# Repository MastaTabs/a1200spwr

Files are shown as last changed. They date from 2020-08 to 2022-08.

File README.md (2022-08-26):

# Amiga1200 single power

This is a DCDC converter Module to fit in Rev. 6a+ Amiga 500 mainboards.
It will be soldered onto the mainboard and one can then use a 12V barrel jack power supply with the Amiga 500.

It can deliver upto 6A @ 5V and 500mA @ -12V. The 12V line is passed through.

It also adds a power switch to the machine on the backside.

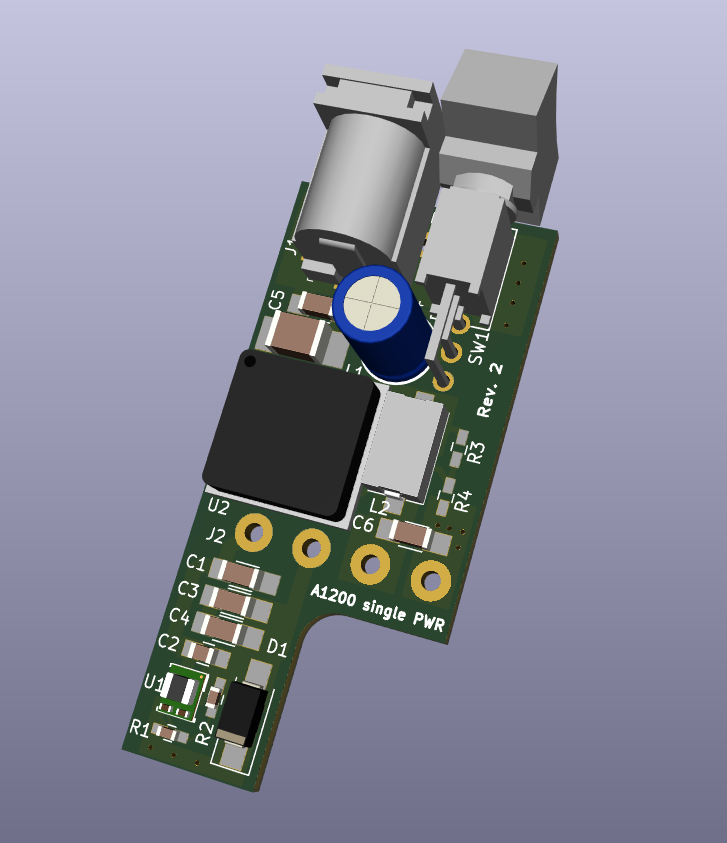
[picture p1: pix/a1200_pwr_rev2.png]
A1200


This design has not been finally tested yet.

### License
The Amiga1200 single power documentation, including the design itself, is copyright © MastaTabs (Tobias Seiler) 2020.

Amiga1200 single power is Open Hardware licensed under the CERN OHL v. 1.2.

You may redistribute and modify this documentation under the terms of the CERN OHL v.1.2. This documentation is distributed as is and WITHOUT ANY EXPRESS OR IMPLIED WARRANTIES whatsoever with respect to its functionality, operability or use, including, without limitation, any implied warranties OF MERCHANTABILITY, SATISFACTORY QUALITY, FITNESS FOR A PARTICULAR PURPOSE or infringement. We expressly disclaim any liability whatsoever for any direct, indirect, consequential, incidental or special damages, including, without limitation, lost revenues, lost profits, losses resulting from business interruption or loss of data, regardless of the form of action or legal theory under which the liability may be asserted, even if advised of the possibility or likelihood of such damages.

A copy of the full license is included in file LICENSE.pdf, please refer to it for applicable conditions. In order to properly deal with its terms, please see file LICENSE_HOWTO.pdf.

The contact points for information about manufactured Products (see section 4.2) are listed in file PRODUCT.md.

Any modifications made by Licensees (see section 3.4.b) shall be recorded in file CHANGES.md.

The Documentation Location of the original project is https://github.com/MastaTabs/a1200spwr.

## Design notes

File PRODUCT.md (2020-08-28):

## Manufacture and distribution of Products

Amiga1200 single power is Open Hardware licensed under the CERN OHL v. 1.2.

Following is an excerpt from Section 4 of the [license](LICENSE.pdf) - **Manufacture and distribution of Products** - where *product* means *either an entire, or any part of a, device built using the Documentation or the modified Documentation*:

> 4.1. The Licensee may manufacture or distribute *Products* always provided that, where such manufacture or distribution requires a licence under this Licence the Licensee provides to each recipient of such Products an easy means of accessing a copy of the Documentation or modified Documentation, as applicable, as set out in section 3.

> 4.2. The Licensee is invited to inform any Licensor who has indicated his wish to receive this information about the type, quantity and dates of production of Products the Licensee has (had) manufactured

This file contains a list of the contact point wishing to receive information about manufactured Products.

### (Name) (E-Mail or other contact details)
- MastaTabs <mastatabs@gmail.com>

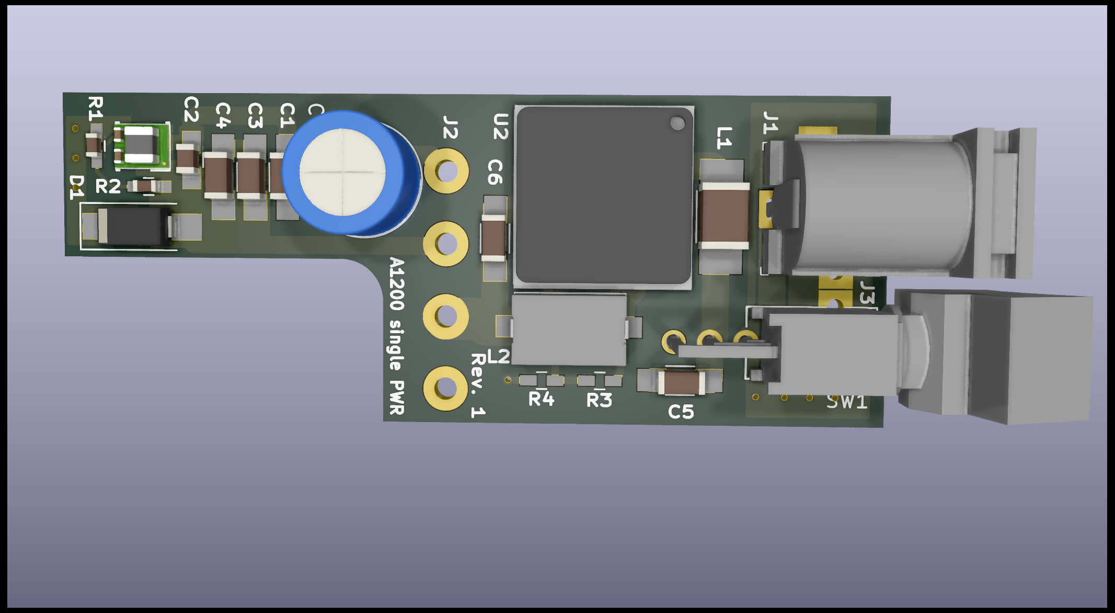
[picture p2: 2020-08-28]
pix/a1200_pwr1.png

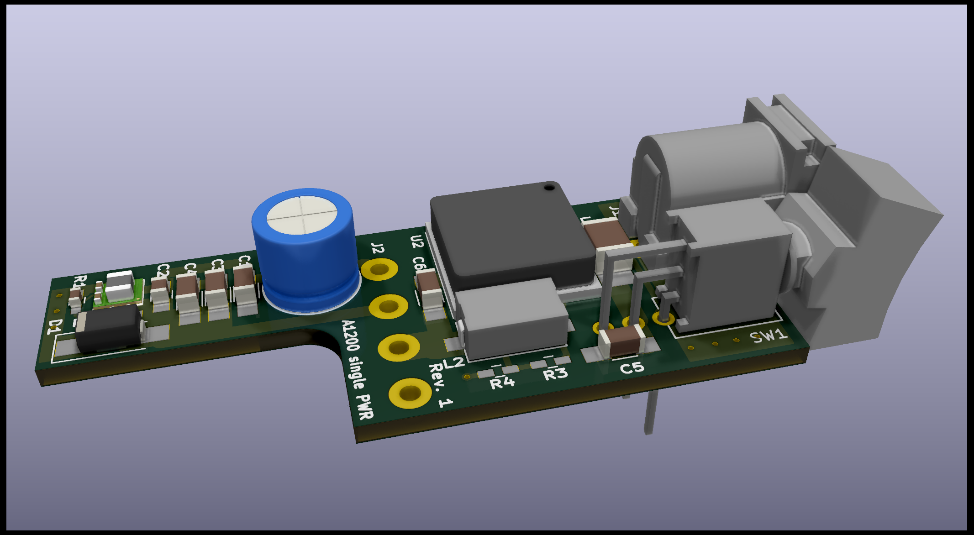
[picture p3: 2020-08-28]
pix/a1200_pwr.png

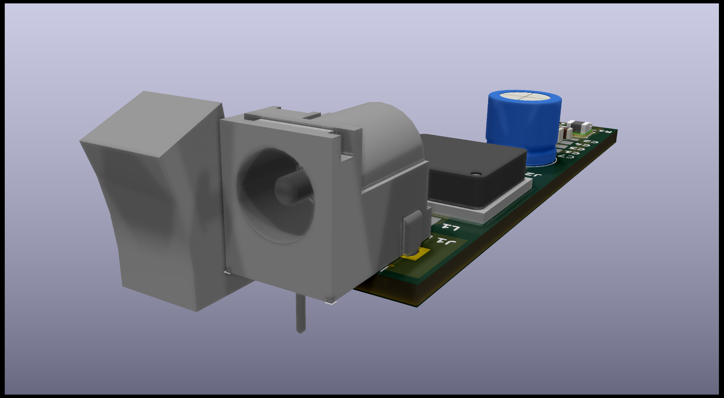
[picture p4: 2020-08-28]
pix/a1200_pwr2.png

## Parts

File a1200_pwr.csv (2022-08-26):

Source: | /home/masta/Desktop/projects/a1200_power/a1200_pwr/a1200_pwr.kicad_sch
Date: | Fr 26 Aug 2022 22:16:40 CEST
Tool: | Eeschema (6.0.7)
Generator: | /usr/share/kicad/plugins/bom_csv_grouped_by_value.py
Component Count: | 20
Individual Components:
<<<<<<< HEAD
Item | Qty | Reference(s) | Value | LibPart | Footprint | Datasheet | Category | DK_Datasheet_Link | DK_Detail_Page | Description | Digi-Key_PN | Family | Herstellernr. | MPN | Manufacturer | Status
 |  | C1 | 10u 25V | Device:C_Small | Capacitors_SMD:C_1206_HandSoldering | https://www.mouser.de/datasheet/2/400/lcc_commercial_general_en-837201.pdf |  |  |  |  |  |  | C3216X5R1H106K160AB
 |  | C2 | 100n 50V | Device:C_Small | Capacitors_SMD:C_0805_HandSoldering | C2012X7R2A104K125AA
 |  | C3 | 10u | Device:C_Small | Capacitors_SMD:C_1206_HandSoldering | CGA5L1X7R1V106K160AC
 |  | C4 | 10u | Device:C_Small | Capacitors_SMD:C_1206_HandSoldering | CGA5L1X7R1V106K160AC
 |  | C5 | 10u 25V | Device:C_Small | Capacitors_SMD:C_1206_HandSoldering | C3216X5R1H106K160AB
 |  | C6 | 22u | Device:C_Small | Capacitors_SMD:C_1206_HandSoldering | C3216X5R1V226M160AC
 |  | C7 | 330u | Device:C | Capacitors_THT:CP_Radial_D8.0mm_P3.50mm | ~
 |  | D1 | 700mV | Device:D_Schottky_Small | Diodes_SMD:D_SMA_Handsoldering | B360A-13-F
 |  | J1 | PJ-102A | barreljack:PJ-102A | a1200_pwr:Barrel_Jack_5.5mmODx2.1mmID_PJ-102A | https://www.cui.com/product/resource/digikeypdf/pj-102a.pdf | Connectors, Interconnects | https://www.cui.com/product/resource/digikeypdf/pj-102a.pdf | /product-detail/en/cui-inc/PJ-102A/CP-102A-ND/275425 | CONN PWR JACK 2X5.5MM SOLDER | CP-102A-ND | Barrel - Power Connectors |  | PJ-102A | CUI Inc. | Active
 |  | J2 | APWR_big | a1200_pwr-rescue:Conn_01x04-connect | a1200_pwr:APWR_big | ~
 |  | J3 | APWR_small | a1200_pwr-rescue:Conn_01x03-connect | a1200_pwr:APWR_small | ~ | Connectors, Headers
 |  | L1 | 742792510 | Device:Ferrite_Bead_Small | Capacitors_SMD:C_1812_HandSoldering | https://www.mouser.de/datasheet/2/445/742792510-1720733.pdf |  |  |  |  |  |  |  |  | Würth
 |  | L2 | 7427932 | Device:Ferrite_Bead_Small | a500_pwr:fb_5v | https://www.mouser.de/datasheet/2/445/7427932-1720978.pdf |  |  |  |  |  |  |  |  | Würth
 |  | R1 | 280k 1% | Device:R_Small | Capacitors_SMD:C_0603_HandSoldering | https://www.mouser.de/datasheet/2/427/dcrcwe3-45987.pdf |  |  |  |  |  |  | CRCW0603280KFKEA
 |  | R2 | 25.5k | Device:R_Small | Capacitors_SMD:C_0603_HandSoldering | https://www.mouser.de/datasheet/2/427/dcrcwe3-45987.pdf |  |  |  |  |  |  | CRCW060325K5FKEA
 |  | R3 | Rdown | Device:R_Small | Capacitors_SMD:C_0603_HandSoldering
 |  | R4 | Rup | Device:R_Small | Capacitors_SMD:C_0603_HandSoldering
 |  | SW1 | RMS1R102M7QES | a1200_pwr:PWR_SW | a1200_pwr:rock_sw | https://www.mouser.de/datasheet/2/418/NG_CD_2267087_A_2267087_c.dwg-680380.pdf
 |  | U1 | LMZM23600SILR | a1200_pwr:LMZM23601SILR | a1200_pwr:SIL0010A | http://www.ti.com/general/docs/suppproductinfo.tsp?distId=26
 |  | U2 | RPM5.0-6.0 | a1200_pwr:RPM5.0-6.0 | a1200_pwr:RPM5.0-6.0 | https://www.mouser.de/datasheet/2/468/RPM-6.0-1398219.pdf
=======
Item | Qty | Reference(s) | Value | LibPart | Footprint | Datasheet | Category | DK_Datasheet_Link | DK_Detail_Page | Datasheet | Description | Digi-Key_PN | Family | MPN | Manufacturer | Reference | Status | Value
 |  | C1 | 10u 25V | Device:C_Small |  | https://www.mouser.de/datasheet/2/400/lcc_commercial_general_en-837201.pdf |  |  |  | https://www.mouser.de/datasheet/2/400/lcc_commercial_general_en-837201.pdf |  |  |  | C3216X5R1H106K160AB |  | C1 |  | C_Small
 |  | C2 | 100n 50V | Device:C_Small |  | C2012X7R2A104K125AA |  |  |  | ~ |  |  |  | C2012X7R2A104K125AA |  | C2 |  | C_Small
 |  | C3 | 10u | Device:C_Small |  | CGA5L1X7R1V106K160AC |  |  |  | ~ |  |  |  | CGA5L1X7R1V106K160AC |  | C3 |  | C_Small
 |  | C4 | 10u | Device:C_Small |  | CGA5L1X7R1V106K160AC |  |  |  | ~ |  |  |  | CGA5L1X7R1V106K160AC |  | C4 |  | C_Small
 |  | C5 | 10u 50V | Device:C_Small | Capacitors_SMD:C_1206_HandSoldering | C3216X5R1H106K160AB |  |  |  | ~ |  |  |  | C3216X5R1H106K160AB |  | C5 |  | 10u 50V
 |  | C6 | 22u 35V | Device:C_Small | Capacitors_SMD:C_1206_HandSoldering | https://product.tdk.com/system/files/dam/doc/product/capacitor/ceramic/mlcc/catalog/mlcc_commercial_general_en.pdf |  |  |  | https://product.tdk.com/system/files/dam/doc/product/capacitor/ceramic/mlcc/catalog/mlcc_commercial_general_en.pdf |  |  |  | C3216X5R1C226M160AB | TDK | C6 |  | 22u 35V
 |  | C7 | 330u | Device:C | Capacitor_THT:CP_Radial_D6.3mm_P2.50mm | https://www.mouser.de/datasheet/2/445/860160373021-1725922.pdf |  |  |  | https://www.mouser.de/datasheet/2/445/860160373021-1725922.pdf |  |  |  | 860160373021 | Wuerth | C7 |  | 330u
 |  | D1 | 700mV | Device:D_Schottky_Small |  | B360A-13-F |  |  |  | ~ |  |  |  | B360A-13-F | Diodes Incorporated | D1 |  | D_Schottky_Small
 |  | J1 | PJ-102A | barreljack:PJ-102A | digikey-footprints:Barrel_Jack_5.5mmODx2.1mmID_PJ-102A | https://www.cui.com/product/resource/digikeypdf/pj-102a.pdf | Connectors, Interconnects | https://www.cui.com/product/resource/digikeypdf/pj-102a.pdf | /product-detail/en/cui-inc/PJ-102A/CP-102A-ND/275425 | https://www.cui.com/product/resource/digikeypdf/pj-102a.pdf | CONN PWR JACK 2X5.5MM SOLDER | CP-102A-ND | Barrel - Power Connectors | PJ-102A | CUI Inc. | J1 | Active | PJ-102A
 |  | J2 | APWR_big | a1200_pwr-rescue:Conn_01x04-connect |  |  |  |  |  |  |  |  |  |  |  | J2 |  | Conn_01x04-connect
 |  | J3 | APWR_small | a1200_pwr-rescue:Conn_01x03-connect |  |  | Connectors, Headers |  |  |  |  |  |  |  |  | J3 |  | Conn_01x03-connect
 |  | L1 | 742792510 | a1200_pwr-rescue:Ferrite_Bead_Small-Device | Capacitors_SMD:C_1812_HandSoldering | https://www.mouser.de/datasheet/2/445/742792510-1720733.pdf |  |  |  | https://www.mouser.de/datasheet/2/445/742792510-1720733.pdf |  |  |  | 742792510 | Würth | L1 |  | 742792510
 |  | L2 | 7427932 | a1200_pwr-rescue:Ferrite_Bead_Small-Device | a500_pwr:fb_5v | https://www.mouser.de/datasheet/2/445/7427932-1720978.pdf |  |  |  | https://www.mouser.de/datasheet/2/445/7427932-1720978.pdf |  |  |  | 7427932 | Würth | L2 |  | 7427932
 |  | R1 | 280k 1% | Device:R_Small |  | https://www.mouser.de/datasheet/2/427/dcrcwe3-45987.pdf |  |  |  | https://www.mouser.de/datasheet/2/427/dcrcwe3-45987.pdf |  |  |  | CRCW0603280KFKEA |  | R1 |  | R_Small
 |  | R2 | 25.5k | Device:R_Small |  | https://www.mouser.de/datasheet/2/427/dcrcwe3-45987.pdf |  |  |  | https://www.mouser.de/datasheet/2/427/dcrcwe3-45987.pdf |  |  |  | CRCW060325K5FKEA |  | R2 |  | R_Small
 |  | R3 | Rdown | Device:R_Small |  | ~ |  |  |  | ~ |  |  |  |  |  | R3 |  | R_Small
 |  | R4 | Rup | Device:R_Small |  | ~ |  |  |  | ~ |  |  |  |  |  | R4 |  | R_Small
 |  | SW1 | SW_SPDT | Switch:SW_SPDT | a1200_pwr:rock_sw | https://www.mouser.de/datasheet/2/418/NG_CD_2267087_A_2267087_c.dwg-680380.pdf |  |  |  | https://www.mouser.de/datasheet/2/418/NG_CD_2267087_A_2267087_c.dwg-680380.pdf |  |  |  | RMS1R102M7QES |  | SW1 |  | SW_SPDT
 |  | U1 | LMZM23600SILR | a1200_pwr-rescue:LMZM23601SILR-a1200_pwr |  | http://www.ti.com/general/docs/suppproductinfo.tsp?distId=26 |  |  |  | http://www.ti.com/general/docs/suppproductinfo.tsp?distId=26 |  |  |  | lmzm23600 | Texas Instruments | U1 |  | LMZM23601SILR-a1200_pwr
 |  | U2 | RPM5.0-6.0 | a1200_pwr:RPM5.0-6.0 | a500_pwr:RPM5.0-6.0 | https://www.mouser.de/datasheet/2/468/RPM-6.0-1398219.pdf |  |  |  | https://www.mouser.de/datasheet/2/468/RPM-6.0-1398219.pdf |  |  |  | RPM5.0-6.0 | RECOM Power | U2 |  | RPM5.0-6.0
>>>>>>> bf3d058 (Revision 2)
Collated Components:
Item | Qty | Reference(s) | Value | LibPart | Footprint | Datasheet | Category | DK_Datasheet_Link | DK_Detail_Page | Datasheet | Description | Digi-Key_PN | Family | MPN | Manufacturer | Reference | Status | Value
1 | 1 | C1 | 10u 25V | Device:C_Small |  | https://www.mouser.de/datasheet/2/400/lcc_commercial_general_en-837201.pdf |  |  |  | https://www.mouser.de/datasheet/2/400/lcc_commercial_general_en-837201.pdf |  |  |  | C3216X5R1H106K160AB |  | C1 |  | C_Small
2 | 1 | C2 | 100n 50V | Device:C_Small |  | C2012X7R2A104K125AA |  |  |  | ~ |  |  |  | C2012X7R2A104K125AA |  | C2 |  | C_Small
3 | 2 | C3, C4 | 10u | Device:C_Small |  | CGA5L1X7R1V106K160AC |  |  |  | ~ |  |  |  | CGA5L1X7R1V106K160AC |  | C3 |  | C_Small
4 | 1 | C5 | 10u 50V | Device:C_Small | Capacitors_SMD:C_1206_HandSoldering | C3216X5R1H106K160AB |  |  |  | ~ |  |  |  | C3216X5R1H106K160AB |  | C5 |  | 10u 50V
5 | 1 | C6 | 22u 35V | Device:C_Small | Capacitors_SMD:C_1206_HandSoldering | https://product.tdk.com/system/files/dam/doc/product/capacitor/ceramic/mlcc/catalog/mlcc_commercial_general_en.pdf |  |  |  | https://product.tdk.com/system/files/dam/doc/product/capacitor/ceramic/mlcc/catalog/mlcc_commercial_general_en.pdf |  |  |  | C3216X5R1C226M160AB | TDK | C6 |  | 22u 35V
6 | 1 | C7 | 330u | Device:C | Capacitor_THT:CP_Radial_D6.3mm_P2.50mm | https://www.mouser.de/datasheet/2/445/860160373021-1725922.pdf |  |  |  | https://www.mouser.de/datasheet/2/445/860160373021-1725922.pdf |  |  |  | 860160373021 | Wuerth | C7 |  | 330u
7 | 1 | D1 | 700mV | Device:D_Schottky_Small |  | B360A-13-F |  |  |  | ~ |  |  |  | B360A-13-F | Diodes Incorporated | D1 |  | D_Schottky_Small
8 | 1 | J1 | PJ-102A | barreljack:PJ-102A | digikey-footprints:Barrel_Jack_5.5mmODx2.1mmID_PJ-102A | https://www.cui.com/product/resource/digikeypdf/pj-102a.pdf | Connectors, Interconnects | https://www.cui.com/product/resource/digikeypdf/pj-102a.pdf | /product-detail/en/cui-inc/PJ-102A/CP-102A-ND/275425 | https://www.cui.com/product/resource/digikeypdf/pj-102a.pdf | CONN PWR JACK 2X5.5MM SOLDER | CP-102A-ND | Barrel - Power Connectors | PJ-102A | CUI Inc. | J1 | Active | PJ-102A
9 | 1 | J2 | APWR_big | a1200_pwr-rescue:Conn_01x04-connect |  |  |  |  |  |  |  |  |  |  |  | J2 |  | Conn_01x04-connect
10 | 1 | J3 | APWR_small | a1200_pwr-rescue:Conn_01x03-connect |  |  | Connectors, Headers |  |  |  |  |  |  |  |  | J3 |  | Conn_01x03-connect
11 | 1 | L1 | 742792510 | a1200_pwr-rescue:Ferrite_Bead_Small-Device | Capacitors_SMD:C_1812_HandSoldering | https://www.mouser.de/datasheet/2/445/742792510-1720733.pdf |  |  |  | https://www.mouser.de/datasheet/2/445/742792510-1720733.pdf |  |  |  | 742792510 | Würth | L1 |  | 742792510
12 | 1 | L2 | 7427932 | a1200_pwr-rescue:Ferrite_Bead_Small-Device | a500_pwr:fb_5v | https://www.mouser.de/datasheet/2/445/7427932-1720978.pdf |  |  |  | https://www.mouser.de/datasheet/2/445/7427932-1720978.pdf |  |  |  | 7427932 | Würth | L2 |  | 7427932
13 | 1 | R1 | 280k 1% | Device:R_Small |  | https://www.mouser.de/datasheet/2/427/dcrcwe3-45987.pdf |  |  |  | https://www.mouser.de/datasheet/2/427/dcrcwe3-45987.pdf |  |  |  | CRCW0603280KFKEA |  | R1 |  | R_Small
14 | 1 | R2 | 25.5k | Device:R_Small |  | https://www.mouser.de/datasheet/2/427/dcrcwe3-45987.pdf |  |  |  | https://www.mouser.de/datasheet/2/427/dcrcwe3-45987.pdf |  |  |  | CRCW060325K5FKEA |  | R2 |  | R_Small
15 | 1 | R3 | Rdown | Device:R_Small |  | ~ |  |  |  | ~ |  |  |  |  |  | R3 |  | R_Small
16 | 1 | R4 | Rup | Device:R_Small |  | ~ |  |  |  | ~ |  |  |  |  |  | R4 |  | R_Small
17 | 1 | SW1 | SW_SPDT | Switch:SW_SPDT | a1200_pwr:rock_sw | https://www.mouser.de/datasheet/2/418/NG_CD_2267087_A_2267087_c.dwg-680380.pdf |  |  |  | https://www.mouser.de/datasheet/2/418/NG_CD_2267087_A_2267087_c.dwg-680380.pdf |  |  |  | RMS1R102M7QES |  | SW1 |  | SW_SPDT
18 | 1 | U1 | LMZM23600SILR | a1200_pwr-rescue:LMZM23601SILR-a1200_pwr |  | http://www.ti.com/general/docs/suppproductinfo.tsp?distId=26 |  |  |  | http://www.ti.com/general/docs/suppproductinfo.tsp?distId=26 |  |  |  | lmzm23600 | Texas Instruments | U1 |  | LMZM23601SILR-a1200_pwr
19 | 1 | U2 | RPM5.0-6.0 | a1200_pwr:RPM5.0-6.0 | a500_pwr:RPM5.0-6.0 | https://www.mouser.de/datasheet/2/468/RPM-6.0-1398219.pdf |  |  |  | https://www.mouser.de/datasheet/2/468/RPM-6.0-1398219.pdf |  |  |  | RPM5.0-6.0 | RECOM Power | U2 |  | RPM5.0-6.0

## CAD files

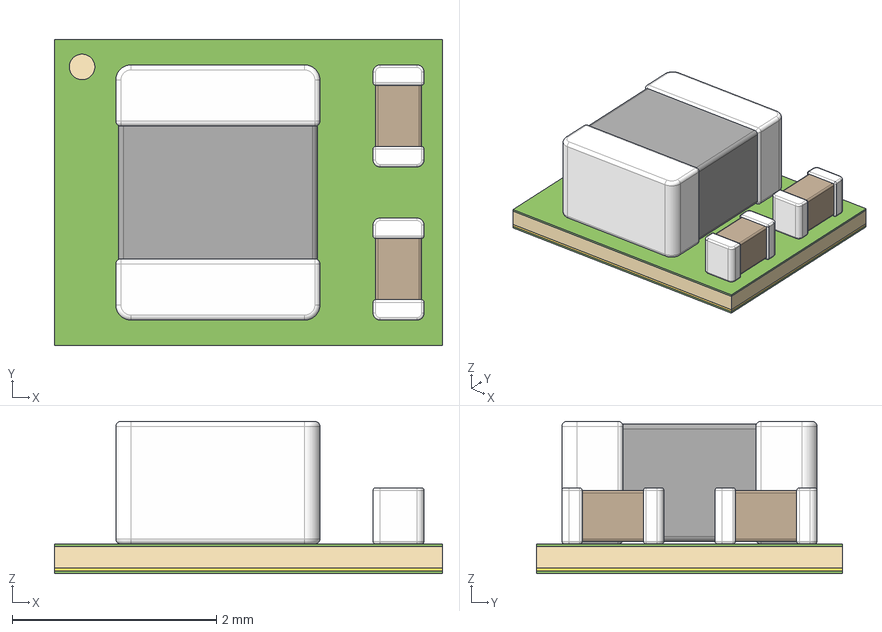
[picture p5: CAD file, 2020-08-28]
3d/SIL0010A.stp
3.80 x 3.00 x 1.49 mm
SOLDERMASK-BTM-SIL0010A
METAL-SIP
SUBSTRATE-SIP
SOLDERMASK-TOP
INDUCTOR-BODY
INDUCTOR-TERMNL x 2
CAP-BODY x 2
CAP-TERMNL x 4

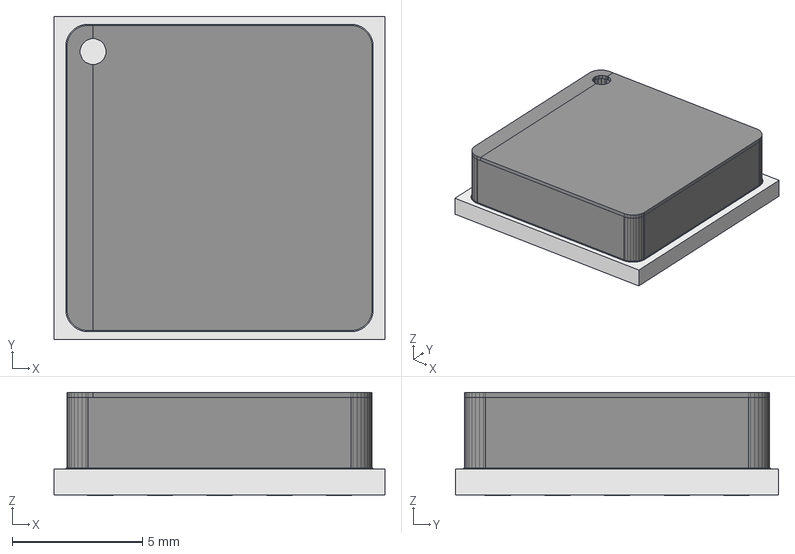
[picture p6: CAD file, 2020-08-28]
3d/RPM-6.0.step
12.7 x 12.4 x 3.97 mm
Extruded.step x 2
Extruded-0.step x 2
Extruded-1.step x 2
Extruded-2.step x 2
Extruded-3.step x 2
Extruded-4.step x 2
Extruded-5.step003 x 4
Extruded-6.step003 x 4
RPM_RBB_PCB028
RPM_RBB_PCB029
RPM_RBB_PCB030
RPM_RBB_PCB031
RPM_RBB_PCB032
RPM_RBB_PCB033
RPM_RBB_PCB034
RPM_RBB_PCB035
RPM_RBB_PCB036
RPM_RBB_PCB037
RPM_RBB_PCB038
RPM_RBB_PCB039
RPM_RBB_PCB040
RPM_RBB_PCB041
RPM_RBB_PCB042
RPM_RBB_PCB043
RPM_RBB_PCB044
RPM_RBB_PCB045
RPM_RBB_PCB046
RPM_RBB_PCB047
RPM_RBB_PCB048
RPM_RBB_PCB049
RPM_RBB_PCB050
RPM_RBB_PCB051
RPM_RBB_PCB052
RPM_RBB_PCB053
RPM_RBB_PCB054
RPM_RBB_PCB
RPM_RBB_PCB001
RPM_RBB_PCB002
RPM_RBB_PCB003
RPM_RBB_PCB004
RPM_RBB_PCB005
RPM_RBB_PCB006
RPM_RBB_PCB007
RPM_RBB_PCB008
RPM_RBB_PCB009
RPM_RBB_PCB010
RPM_RBB_PCB011
RPM_RBB_PCB012
RPM_RBB_PCB013
RPM_RBB_PCB014
RPM_RBB_PCB015
RPM_RBB_PCB016
RPM_RBB_PCB017
RPM_RBB_PCB018
RPM_RBB_PCB019
RPM_RBB_PCB020
RPM_RBB_PCB021
RPM_RBB_PCB022
RPM_RBB_PCB023
RPM_RBB_PCB024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

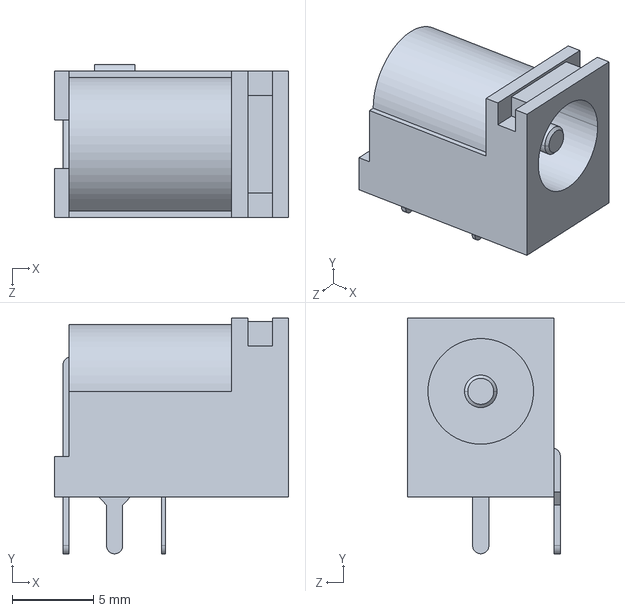
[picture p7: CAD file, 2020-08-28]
3d/CUI_DEVICES_PJ-102A.step
14.4 x 14.5 x 9.40 mm

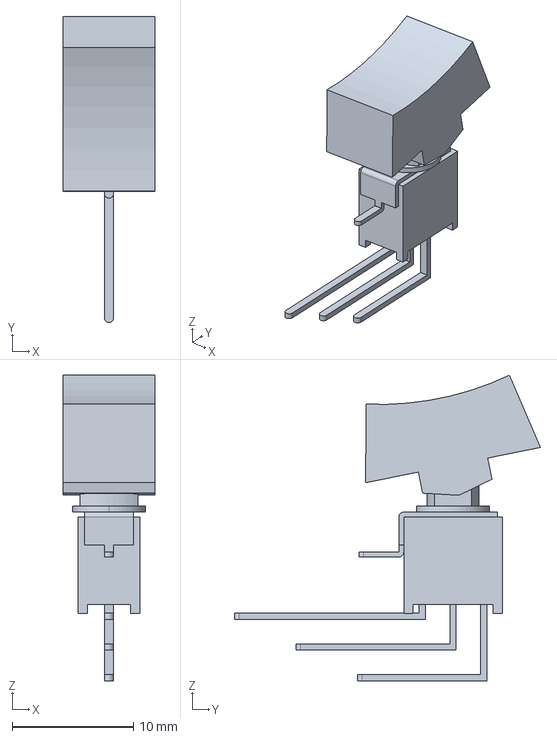
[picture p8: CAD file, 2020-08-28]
3d/c-2267087-5-a-3d.stp
7.62 x 25.3 x 25.2 mm

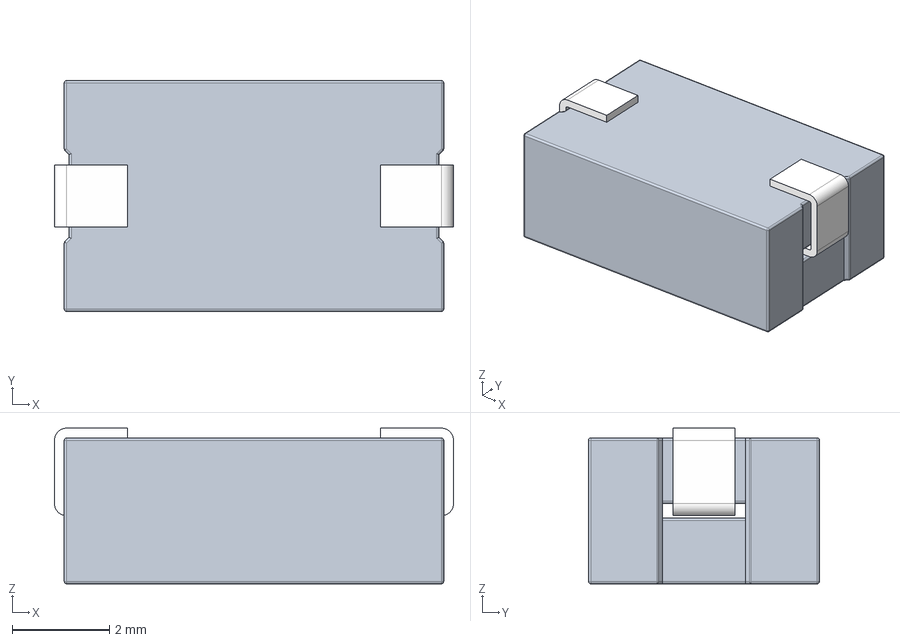
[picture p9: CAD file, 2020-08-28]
3d/7427932 (rev1).stp
8.20 x 4.75 x 3.20 mm

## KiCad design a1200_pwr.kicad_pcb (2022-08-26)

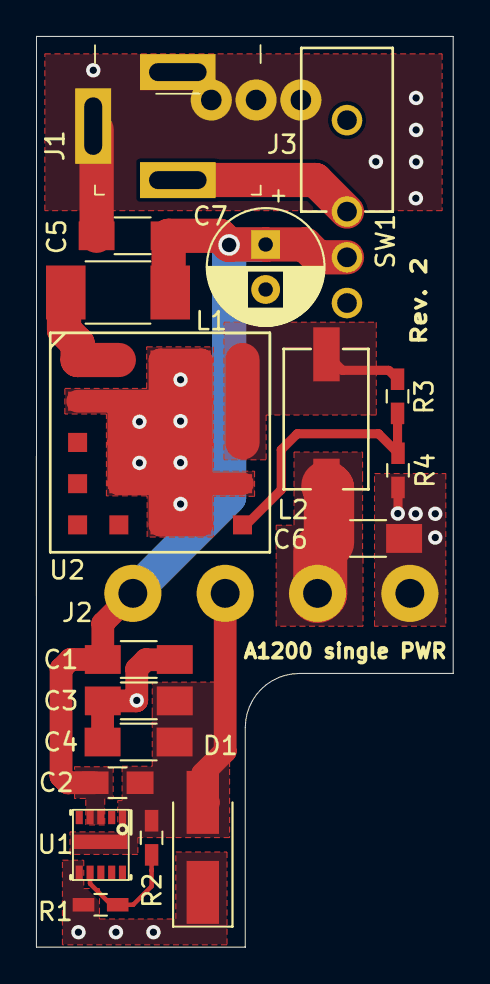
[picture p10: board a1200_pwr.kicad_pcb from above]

Board: 2 copper layers, 23.2 x 50.6 mm, 20 parts (0 on the bottom side), 9 nets.

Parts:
C1, C5: 10u 25V; C_1206_HandSoldering
C2: 100n 50V; C_0805_HandSoldering
C3, C4: 10u; C_1206_HandSoldering
C6: 22u; C_1206_HandSoldering
C7: 330u; CP_Radial_D6.3mm_P2.50mm
D1: 700mV; D_SMA_Handsoldering
J1: PJ-102A; Barrel_Jack_5.5mmODx2.1mmID_PJ-102A
J2: APWR_big
J3: APWR_small
L1: 742792510; C_1812_HandSoldering
L2: 7427932; fb_5v
R1: 280k 1%; C_0603_HandSoldering
R2: 25.5k; C_0603_HandSoldering
R3: Rdown; C_0603_HandSoldering
R4: Rup; C_0603_HandSoldering
SW1: SW_SPDT; rock_sw
U1: LMZM23600SILR; SIL0010A
U2: RPM5.0-6.0

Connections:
+5V: C6.1, J2.3, L2.1
+12V: C1.1, C2.1, C5.1, C7.1, J2.1, L1.2, SW1.2 (B), U1.3 (Vin), U1.4 (EN)
-12V: C2.2, C3.2, C4.2, D1.2 (A), J2.2, R2.2, U1.1 (GND), U1.11 (PAD)
/5Vout: L2.2, R3.2, U2.A5 (Vout), U2.B5 (Vout), U2.C5 (Sense)
/SW12V: J1.1, SW1.1 (A)
GND: C1.2, C3.1, C4.1, C5.2, C6.2, C7.2, D1.1 (K), J1.2, J1.3, J2.4, J3.1, J3.2, J3.3, R1.1, R4.1, U1.6 (Vout), U2.A3 (GND), U2.A4 (GND), U2.B1 (GND), U2.B2 (GND), U2.B3 (GND), U2.B4 (GND), U2.C2 (GND), U2.C3 (GND), U2.C4 (GND), U2.D2 (GND), U2.D3 (GND), U2.D4 (GND), U2.D5 (GND), U2.E3 (GND), U2.E4 (GND)
unnamed: L1.1, U2.A1 (Vin), U2.A2 (Vin)
unnamed: R1.2, R2.1, U1.7 (FB)
unnamed: R3.1, R4.2, U2.E5 (Trim)

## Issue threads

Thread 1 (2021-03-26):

Clarification on value of C6

MadMungo, 2021-03-26:
In the BOM & cct diagram it has C6 down as 22uF but the part # C3216X5R1H106K106AB is for a 50V 10uF capacitor.
The part # for the 35V 22uF should be C3216X5R1V226M160AC.
Just need to know if that 22uF value is correct.

MastaTabs, 2021-03-27:
You are right. Thats a mistake on my side. It should be 22µF.

Closed 2022-12-08.

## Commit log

2020-08-28 fixed 3d view
    [a1200_pwr.kicad_pcb]
2020-08-29 small top overlay fixes
    [a1200_pwr-B_Cu.gbl, a1200_pwr-B_Mask.gbs, a1200_pwr-B_Paste.gbp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]
2020-09-08 the PGOOD pin of the LMZM23600 was numbered 11 but 5 buy mistake, now the planes are correctly drawn without manual connect of the center pad
    [a1200_pwr.kicad_pcb, a1200_pwr.sch]
2020-09-08 new gerbers
    [a1200_pwr-B_Cu.gbl, a1200_pwr-B_Mask.gbs, a1200_pwr-B_Paste.gbp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]
2021-03-27 Update a1200_pwr.sch
    fix 22µF part number.
    [a1200_pwr.sch]
2021-03-27 fix C6 Part number
    [a1200_pwr.csv]
2022-08-26 Revision 2
    [a1200_pwr.kicad_sch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]
2022-08-26 fix front silkscreen for L2
    [a1200_pwr.kicad_pcb]
2022-08-26 regen gerbers
    [a1200_pwr-B_Cu.gbl, a1200_pwr-B_Mask.gbs, a1200_pwr-B_Paste.gbp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]
